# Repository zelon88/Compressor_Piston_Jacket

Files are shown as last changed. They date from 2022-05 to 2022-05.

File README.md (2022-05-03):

# Compressor_Piston_Jacket
In this repo you will find a 3D printable retrofit kit for installing the piston & connecting rod from a $9.99 Pittsburg Automotive "12V Portable Inflator" Model 63152, 4077, 61740, or 63109 from Harbor Freight Tools into an EverStart MAXX Model J5CPDE air compressor.

The EverStart MAXX Model J5CPDE is an excellent little 12v automotive jump-starter with integrated air compressor, USB ports, spotlight, and 110v AC inverter. While the quality of the unit is very high overall, the compressor uses a plastic reciprocating assembly (piston & connecting rod) which can fail over time.

The Pittsburg Automotive "12V Portable Inflator" Model 63152, 4077, 61740, or 63109 is a 12v compatible air inflator with a steel reciprocating assembly and similar dimensions. At $9.99 the price is right for using this unit as a "repair kit" for a failed EverStart MAXX Model J5CPDE air compressor.

Along with the original source code files in .scad format you will also find renderings of each component and detailed 3D printing, manufacturing & assembly instructions.

DETAILED RETROFIT INSTRUCTIONS COMING SOON!

---

# Features
* Pittsburg piston fits inside the Piston Jacket.
* Window Inserts secure the Piston Jacket to the piston.
* Entire Pittsburg piston & connecting rod, piston jacket, & window inserts install into the integrated compressor of the EverStart MAXX Model J5CPDE.
* Replaces the stock plastic piston & connecting rod assembly with a plastic wrapped steel piston & steel connecting rod.
* Seals using the pre-installed Pittsburg gasket.

# Component Description
* CPJ-001 is the "Piston Jacket" that wraps around the steel Pittsburg piston.
* CPJ-002 is a complete set of 4 identical "Window Inserts" which secure the piston jacket onto the piston.
* CPJ-003 is a complete "Piston Jacket" with "Window Inserts" installed. This model demonstrates what the final product should look like.

# Notes
* If you like this design consider following & sponsoring me on Github, or other social media @zelon88.

# Pictures
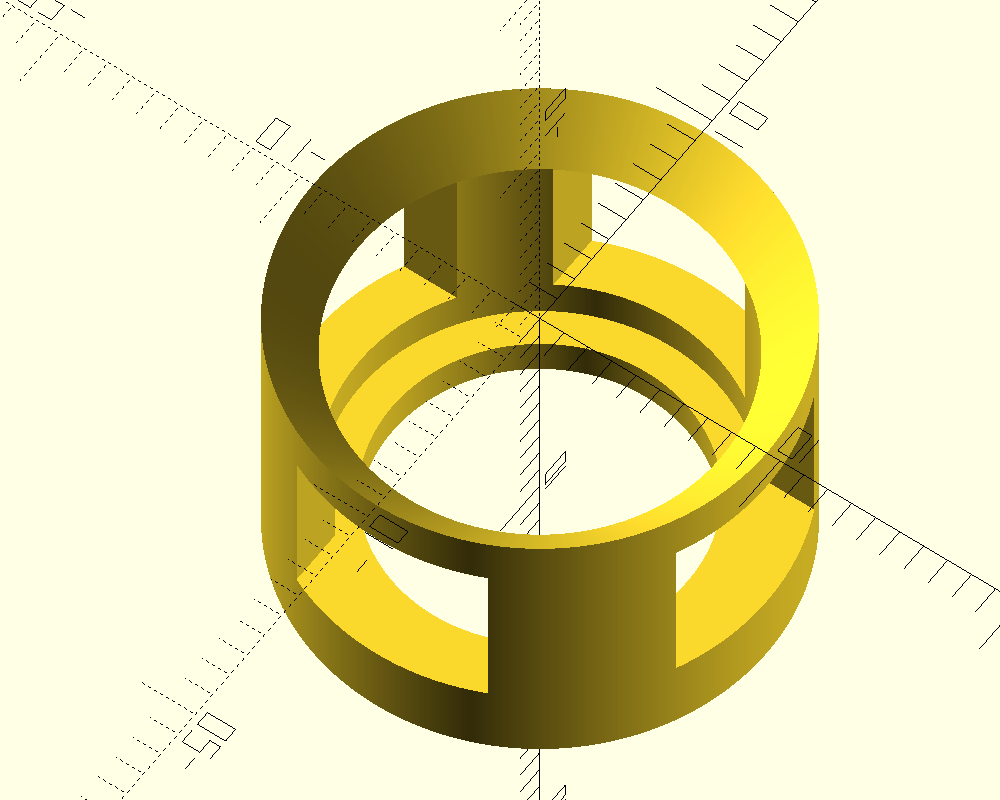
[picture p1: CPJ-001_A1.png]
Compressor_Piston_Jacket-001

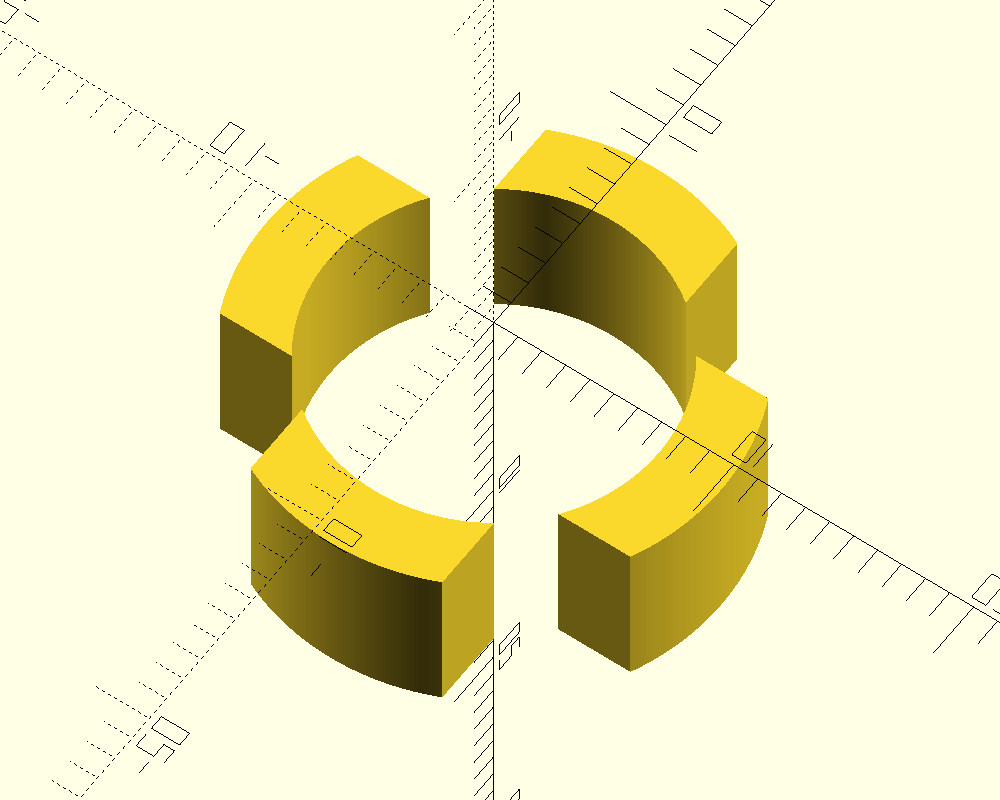
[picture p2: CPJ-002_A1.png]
Compressor_Piston_Jacket-002
	
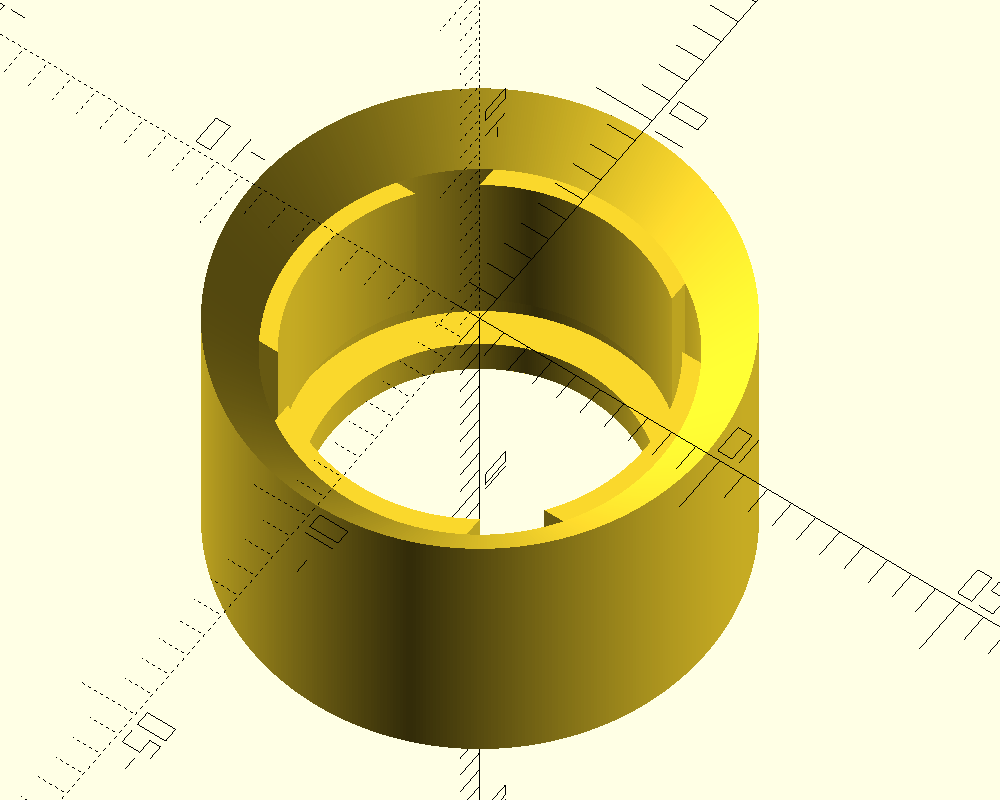
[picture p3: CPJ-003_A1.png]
Compressor_Piston_Jacket-003


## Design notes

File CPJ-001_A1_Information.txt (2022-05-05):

----------------------------------------------------------------------------------------------------
PROJECT INFORMATION

NAME:  Compressor_Piston_Jacket
REVISION:  A1
START DATE:  5/2/2022
CURRENT VERSION DATE:  5/2/2022
LICENSE:  GPLv3
AUTHOR:  Justin Grimes (@zelon88)
DESCRIPTION:  A piston jacket for retrofitting the EverStart MAXX Model J5CPDE air compressor
 with the steel piston & connecting rod from a Pittsburg Automotive Model 63152, 4077, 61740, or 63109
 "12V Portable Inflator" available for $9.99 from Harbor Freight Tools.
----------------------------------------------------------------------------------------------------

----------------------------------------------------------------------------------------------------
PART INFORMATION

NAME:  PISTON JACKET
PART ID:  CPJ-001
REVISION:  A1
START DATE:  5/2/2022
CURRENT VERSION DATE:  5/2/2022
AUTHOR:  Justin Grimes (@zelon88)
DESCRIPTION:  The Piston Jacket serves as the main body of the part. 
 It slides over the piston and features four rectangular windows in the side.
 Once installed on the piston, "CPJ-002" can be installed by press fitting 
 one piece of "CPJ-002" into each of the four windows.
FILE NAME: CPJ-001.scad
----------------------------------------------------------------------------------------------------

----------------------------------------------------------------------------------------------------
PRINTER CONFIGURATION

PRINTER TYPE:  XYZPrinting da Vinci Jr. 1.0A Pro
SLICER:  XYZPrint Version 2.0.21 
NOZZLE DIAMETER:  0.40mm
NOZZLE MATERIAL:  Copper
NOZZLE TEMPERATURE:  210c
NOZZLE FIRST LAYER TEMPERATURE:  215c
LAYER HEIGHT:  0.20mm
FIRST LAYER HEIGHT:  0.35mm
SHELL THICKNESS NORMAL:  2 Layers
SHELL THICKNESS TOP & BOTTOM SURFACE:  5 Layers
INNER SHELLS:  0mm
LIGHTWEIGHT:  No
INFILL DENSITY:  100%
INFILL TYPE:  Gyroid
DETAIL THRESHOLD:  0.001mm
AVOID CROSSING PRINTED PARTS:  No
SHELLS NORMAL SPEED:  30mm/s
SHELLS SURFACE SPEED:  30mm/s
SHELL SMALL RADIUS SPEED:  20mm/s
INFILL NORMAL SPEED:  45mm/s
INFILL TOP SURFACE SPEED:  45mm/s
SOLID INFILL SPEED:  45mm/s
BRIDGE PRINTING SPEED:  20mm/s
NON-PRINTING MOVEMENT SPEED:  50mm/s
BOTTOM LAYER SPEED:  10mm/s
RETRACT SPEED:  30mm/s
AUTO SPEED ADJUSTMENT FOR SMALL PARTS:  No
BRIM:  No
SUPPORTS:  No
RAFT:  No
RETRACT LENGTH:  4.5mm
ACTIVATE THRESHOLD (MIN TRAVEL LENGTH):  2mm
RETRACTION NOZZLE LIFT:  0mm
ADD EXTRA FILAMENT (WHEN TRAVEL < RETRACTION):  0mm
RETRACT EACH LAYER:  Yes
DISABLE RETRACTION CURRENT PERIMETER:  Yes
SHELL EXTRUSION RATIO:  100%
SHELL FILL EXTRUSION RATIO:  100%
INFILL EXTRUSION RATIO:  100%
SEAM CORNER PREFERENCES:  "Smart Hiding"
----------------------------------------------------------------------------------------------------

----------------------------------------------------------------------------------------------------
PARTS LIST

1. 2m PLA Filament
----------------------------------------------------------------------------------------------------

----------------------------------------------------------------------------------------------------
MANUFACTURING INSTRUCTIONS

1. Visually inspect for damage or manufacturing irregularities.
2. File to remove any burrs or rough edges.
3. DO NOT chase any holes with a drill bit.
----------------------------------------------------------------------------------------------------

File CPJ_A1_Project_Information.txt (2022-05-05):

----------------------------------------------------------------------------------------------------
PROJECT INFORMATION

NAME:  Compressor_Piston_Jacket
REVISION:  A1
START DATE:  5/2/2022
CURRENT VERSION DATE:  5/2/2022
LICENSE:  GPLv3
AUTHOR:  Justin Grimes (@zelon88)
DESCRIPTION:  A piston jacket for retrofitting the EverStart MAXX Model J5CPDE air compressor
 with the steel piston & connecting rod from a Pittsburg Automotive Model 63152, 4077, 61740, or 63109
 "12V Portable Inflator" available for $9.99 from Harbor Freight Tools.
----------------------------------------------------------------------------------------------------

----------------------------------------------------------------------------------------------------
PARTS LIST

1x Piston Jacket, CPJ-001 
  2m PLA Filament (2m Total)

1x Window Inserts (4pcs), CPJ-002 
  2m PLA Filament (2m Total)
----------------------------------------------------------------------------------------------------

----------------------------------------------------------------------------------------------------
RETROFIT INSTRUCTIONS

1. Dissassemble the EverStart unit and remove the compressor assembly.
  1a. As shown in "Compressor_Assembly_1.jpg" & "Compressor_Installed_1.jpg".
2. Dissassemble the EverStart compressor assembly and remove any broken pieces.
  2a. As shown in "Compressor_Components_1.jpg".
3. Dissassemble the Pittsburg compressor unit.
  3a. As shown in "Replacement_Parts_3.jpg"
4. Discard the Pittsburg motor, crankcase, crankshaft, sleeve, head, and plastic housing.
5. Ensure the Pittsburg connecting rod and wrist pin are properly assembled as a unit.
6. Any bend in the connecting rod should angle towards the crankshaft when installed.
7. Do not continue with modifications until the Pittspurg piston and connecting rod are assembled.
8. Install "CPJ-001" onto the Pittsurg piston.
9. Install "CPJ-002" (4 piees) into the side windows of "CPJ-001" using a rubber hammer.
10. Using a file or sandpaper, smooth out the outside diamter of the entire piston friction surface.
11. You can test slide the piston into the sleeve, but do not attach the cylinder head yet.
12. The piston will collide with the cylinder head unless the top of the piston is clearanced.
13. Use a file, belt sander, or grinder to grind down the top surface of the piston until it clears.
14. Thoroughly degrease & remove contaminants from all components.
15. Apply a thin layer of automotive grease to the inside of the sleeve.
16. Reinstall the piston & connecting rod into the crankcase.
17. Reinstall the sleeve over the piston.
18. Reinstall the head onto the sleeve.
19. Apply a small bead of automotive grease into the open side of the crankcase.
20. Reinstall the modified EverStart compressor assembly into the EverStart unit.
21. Do not operate the compressor unit for long periods of time.
22. Consider making cooling improvements to the compressor portion of the EverStart rear cover.
----------------------------------------------------------------------------------------------------

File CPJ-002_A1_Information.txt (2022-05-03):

----------------------------------------------------------------------------------------------------
PROJECT INFORMATION

NAME:  Compressor_Piston_Jacket
REVISION:  A1
START DATE:  5/2/2022
CURRENT VERSION DATE:  5/2/2022
LICENSE:  GPLv3
AUTHOR:  Justin Grimes (@zelon88)
DESCRIPTION:  A piston jacket for retrofitting the EverStart MAXX Model J5CPDE air compressor
 with the steel piston & connecting rod from a Pittsburg Automotive Model 63152, 4077, 61740, or 63109
 "12V Portable Inflator" available for $9.99 from Harbor Freight Tools.
----------------------------------------------------------------------------------------------------

----------------------------------------------------------------------------------------------------
PART INFORMATION

NAME:  WINDOW INSERTS
PART ID:  CPJ-002
REVISION:  A1
START DATE:  5/2/2022
CURRENT VERSION DATE:  5/2/2022
AUTHOR:  Justin Grimes (@zelon88)
DESCRIPTION:  The Window Inserts are press fit into the side cutouts of the piston jacket
 and serve to stabilize the piston in the cylinder, prevent piston slap, & act as a friction surface.
FILE NAME: CPJ-002.scad
----------------------------------------------------------------------------------------------------

----------------------------------------------------------------------------------------------------
PRINTER CONFIGURATION

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

----------------------------------------------------------------------------------------------------
PARTS LIST

1. 2m PLA Filament
----------------------------------------------------------------------------------------------------

----------------------------------------------------------------------------------------------------
MANUFACTURING INSTRUCTIONS

1. Visually inspect for damage or manufacturing irregularities.
2. File to remove any burrs or rough edges.
3. DO NOT chase any holes with a drill bit.
----------------------------------------------------------------------------------------------------

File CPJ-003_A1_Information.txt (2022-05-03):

----------------------------------------------------------------------------------------------------
PROJECT INFORMATION

NAME:  Compressor_Piston_Jacket
REVISION:  A1
START DATE:  5/2/2022
CURRENT VERSION DATE:  5/2/2022
LICENSE:  GPLv3
AUTHOR:  Justin Grimes (@zelon88)
DESCRIPTION:  A piston jacket for retrofitting the EverStart MAXX Model J5CPDE air compressor
 with the steel piston & connecting rod from a Pittsburg Automotive Model 63152, 4077, 61740, or 63109
 "12V Portable Inflator" available for $9.99 from Harbor Freight Tools.
----------------------------------------------------------------------------------------------------

----------------------------------------------------------------------------------------------------
PART INFORMATION

NAME:  PISTON JACKET - ASSEMBLY
PART ID:  CPJ-003
REVISION:  A1
START DATE:  5/2/2022
CURRENT VERSION DATE:  5/2/2022
AUTHOR:  Justin Grimes (@zelon88)
DESCRIPTION:  The "Piston Jacket - Assembly" is a complete assembly of all included parts for 
 demonstration purposes.
FILE NAME: CPJ-003_A1.scad
----------------------------------------------------------------------------------------------------

----------------------------------------------------------------------------------------------------
PRINTER CONFIGURATION

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

----------------------------------------------------------------------------------------------------
PARTS LIST

1. 4m PLA Filament
----------------------------------------------------------------------------------------------------

----------------------------------------------------------------------------------------------------
MANUFACTURING INSTRUCTIONS

1. Visually inspect for damage or manufacturing irregularities.
2. File to remove any burrs or rough edges.
3. DO NOT chase any holes with a drill bit.
----------------------------------------------------------------------------------------------------

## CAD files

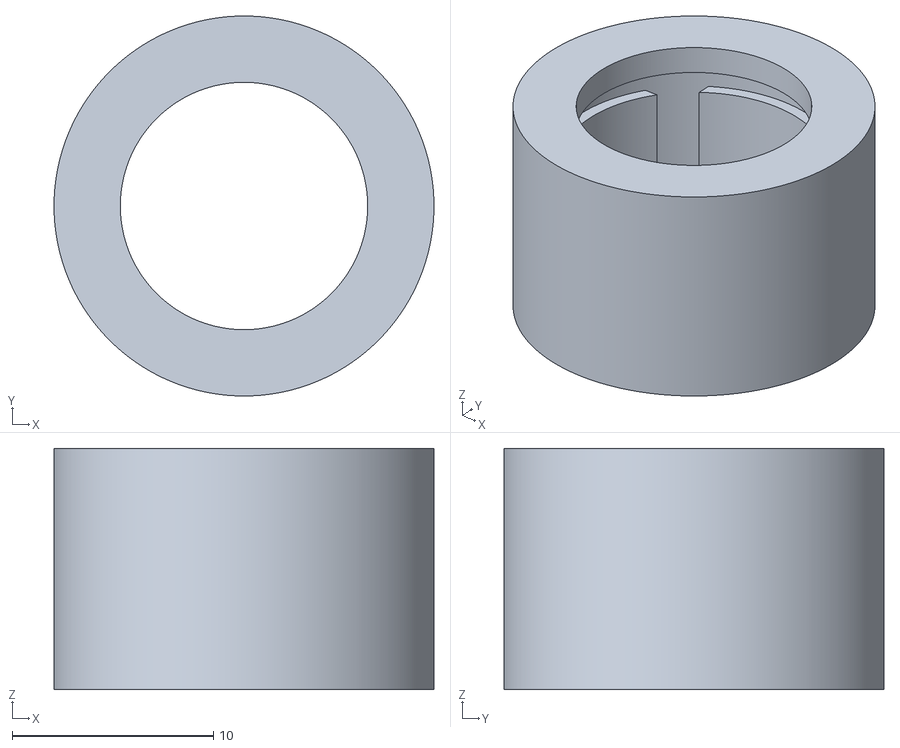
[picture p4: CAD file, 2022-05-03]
CPJ-003_A1.stl
18.9 x 18.9 x 12.0

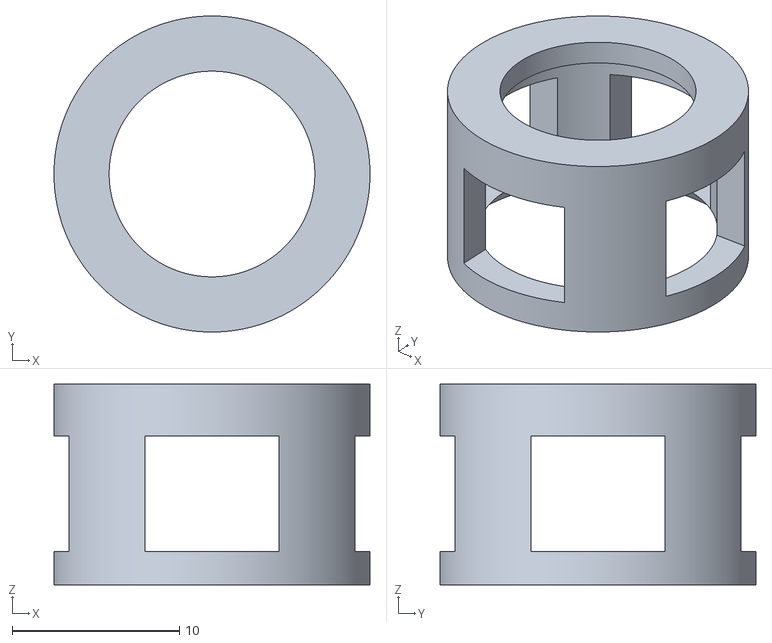
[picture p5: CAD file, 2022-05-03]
CPJ-001_A1.stl
18.9 x 18.9 x 12.0

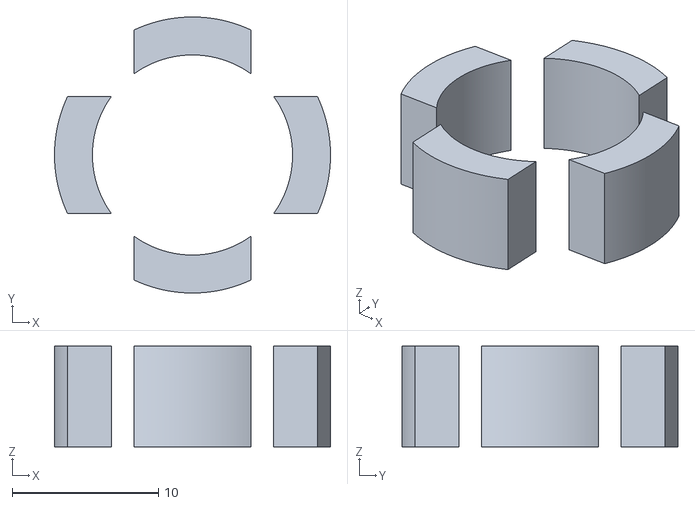
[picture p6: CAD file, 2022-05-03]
CPJ-002_A1.stl
18.9 x 18.9 x 6.90

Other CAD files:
CPJ-001_A1.scad
CPJ-002_A1.scad
CPJ-003_A1.scad
